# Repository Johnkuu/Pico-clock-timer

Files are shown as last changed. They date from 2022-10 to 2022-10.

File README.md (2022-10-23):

# Pico-clock-timer

A Pico based clock with a pomodoro timer. Includes a 3D printable case and two control buttons for keyboard enthusiasts. Powered with USB. No network needed. Uses slightly modified TM1637 library https://github.com/mcauser/micropython-tm1637. 

All necessary files are included in this repo.

## BOM
- Pi Pico
- TM1637.h screen
- 2x led and 2x 330-ohm resistors
- 2x Mechanical keyboard switches and keycaps.
- 3D printable case
- 4x screws (think M3 size) are needed to attach the bottom to the upper case
- Some super glue to attach the screen and leds to the case
- Wire (I used single core)
 
Pico

## Functionality
- On startup says "HIYA" as greeting
- Set time: Hours with left button, minutes with right button. When idling for 5 seconds, the clock starts running. If nothing is done in 5 seconds, sets time to 00.00
- After setting the time left button starts Pomodoro timer with 25 - 5 x4 cycle and ends with a 30-minute break. When it´s working time, the red led shines and during pauses, the blue led shines. When the timer is ready, the led´s goes off. On clock mode, no leds are on.
- When pressing button on right during the Pomodoro cycle the time skips to pause timer (30 min) and second press exits the timer
- The clock keeps the time even during when the pomodoro timer is running
- Adjustable screen light brightness with the left button. When pressing button the blue led blinks. Cycles from dark to brighter and when maxed out, starts from dimmer again.

## ROADMAP
- Better case that doesn´t require glue for attaching the screen.

## PINS:

- Display: CLK=Pin (0), DIO=Pin(1), GND=GND, 5V=VBUS
- LEDs:  ledred = Pin (9), Cathode (-) = GND and ledblue = Pin (27), Cathode (-) = GND (don´t forget the resistor!)
- Buttons: Button1 = Pin (13), GND and button2 = Pin (18), GND

## Instructions:
- Print case (use supports, doesn´t consume time/resources, looks better)
- Attach first the leds in the case with superglue (after setting the screen in place, it might be a slightly tight over there)
- Attach the keyboard switches to the case.
- Solder everything as instructed in PINS section, check everything is working before assembly. Drop all the .py -files into your pico in order to test the funtionality.
- Attach the screen with superglue, bear in your mind that it´s done in the right direction (check the text on the board)
- Attach the Pico to the bottom of the case. I used some filament from the 3D printer and heated the other end to make it flat. Some superglue in the holes in the bottom of the case and the filament through the Pico board holes and into the case holes.

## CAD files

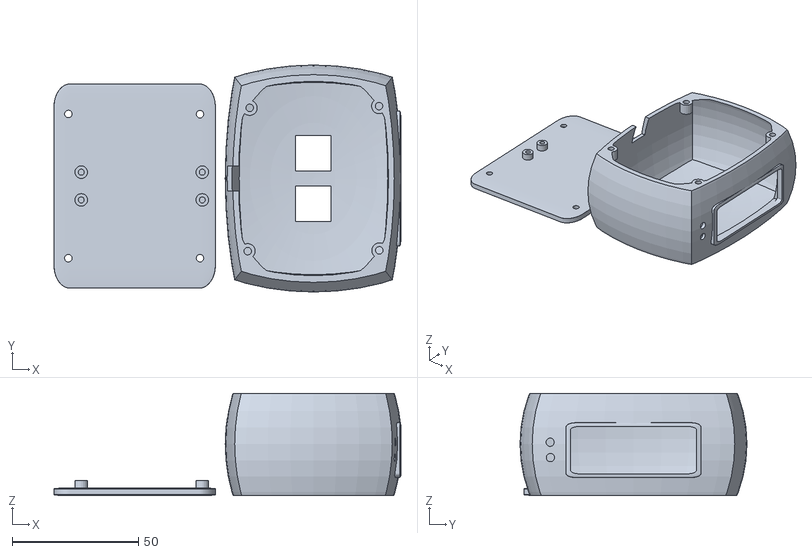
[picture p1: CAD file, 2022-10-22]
Pomodoro_timer_TM1637h.stl
137.6 x 90.0 x 40.5

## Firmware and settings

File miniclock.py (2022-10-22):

import tm1637
from machine import Pin
import time
import led

from machine import RTC

display = tm1637.TM1637(clk=Pin(0), dio=Pin(1))
 
button1 = Pin(13, Pin.IN, Pin.PULL_UP)
button2 = Pin(18, Pin.IN, Pin.PULL_UP)

b = 1 #(brightness of the display)

display.brightness(b) #Set brightness between 1-7)

def set_time():
    rtc = RTC()
#    hour = 20
#    minute = 40
    #rtc.datetime((year, month, day, weekday, hour, minute, second, 0))
    rtc.datetime((2022, 10, 16, 7, hour, minute, 0, 0))

#Clear all
def clear_disp():
    display.show("HIYA")
    time.sleep(1)
    display.show("    ")
    
def clock():
    # get system time
    local_time = str(time.localtime())
    parts = local_time.split(', ')
    hour = int(parts[3])
    minute = int(parts[4])
    second = int(parts[5])

    # Toggle colon when displaying time
    if second % 2:
        # setup HH.MM for display and print it
        display.numbers(hour, minute)
    else:
        # setup HH MM for display and print it
        display.number_time(hour, minute)
    time.sleep(0.5)

#while True:
#    clock()

def pomodore():
    display.show("    ") #tyhjennä näyttö
    rounds = 3 #aseta kierrosten määrä +1
    hour = 25 #aseta kierron aika
    minute = 0 # aseta kierron aika.
    while rounds > 0:
        b1 = button1.value()
        if not b1:
            led.ledredoff()
            break
        led.ledredon()
        display.number_time(hour, minute) # näytä lähtöaika
        hour = 24 #aseta seuraava aika
        minute = 59
        time.sleep(1)
        while True: #aloita kierrosten sisäinen looppi
            b1 = button1.value()
            if hour == 0 and minute == 0: # jos kaikki on nollilla aloita looppi jossa tarkastetaan kierrosten määrä tai hypätään pois
                if rounds == 0:# jos kaikki on nollilla ja kierrokset on nollilla, hyppää loopista pois
                    led.ledredoff()
                    break
                else: #muuten ajan ollessa nollilla laita 5 minuutin tauko käyntiin ja vähennä kierros
                    led.ledblueon()
                    led.ledredoff()
                    rounds -= 1
                    hour = 5
                    minute = 0
                    display.number_time(hour, minute) #Näytä 5 minsaa
                    time.sleep(1)
                    hour = 4 #näytä 4:49
                    minute = 59
                    led.ledblueon()
                    while True:
                        if minute == 0 and hour == 0: #jos minuutti ja sekuntti 0 hyppää pois loopista
                            display.number_time(hour, minute)
                            time.sleep(1)
                            hour = 24 #aseta aika takaisin normaaliin
                            minute = 59
                            break
                        if minute == 0: # jos minuutti 0 vähennä tunti ja aloita minuutti alusta
                            display.number_time(hour, minute)
                            minute = 59
                            hour -= 1
                        if not b1:
                            break
                        else: #muuten näytä aika ja vähennä sekuntti
                            display.number_time(hour, minute)
                        time.sleep(1)
                        minute-= 1
            if minute == 0: #jos vain sekuntit ovat nollilla, vähennä minuutti
                display.number_time(hour, minute)
                minute = 59
                hour -= 1
            if not b1:
                led.ledredoff()
                break    
            else: #muuten vähennä vain sekunti normaalisti
            # setup HH MM for display and print it
                display.number_time(hour, minute)
            time.sleep(1)
            minute-= 1
        hour = 25
        minute = 0
        display.number_time(hour, minute)
#Asettaa taukoajastimen 30 min
        hour = 30
        minute = 0
        display.number_time(hour, minute)
        time.sleep(1)
        hour = 29
        minute = 59
        time.sleep(1)
    
        while True: #Viimeinen 30 minuuttia, jonka jälkeen loppuu 00:00 5 s tauko ja koko silmukka päättyy
            b1 = button1.value()
            led.ledblueon()
            if hour == 0 and minute == 0:
                display.number_time(hour, minute)
                time.sleep(5)
                led.ledblueoff()
                break
            if minute == 0: 
                display.number_time(hour, minute)
                minute = 59
                hour -= 1
            if not b1:
                led.ledblueoff()
                led.ledredoff()
                break    
            else:
            # setup HH MM for display and print it
                display.number_time(hour, minute)
            time.sleep(1)
            minute-= 1
        
def buttons():
    b = 1
    while True:
        b1 = button1.value()
        b2 = button2.value()
        if not b1:
            print("Button 1 pressed!")
            led.ledblueon()
            if b == 7:
                b = 1
                print(b)
            else:
                b += 1
                print(b)
            display.brightness(b) #Set brightness between 1-7)
            time.sleep(0.5)
        if not b2:
            print("Button 2 pressed!")
            pomodore()
        else:
            led.ledblueoff()
            led.ledredoff()
            clock()

def set_time_manually():
    global hour
    global minute
    hour = 0
    minute = 0
    rounds = 0
    while True:
        b1 = button1.value()
        b2 = button2.value()   
        if not b2:
            hour = hour + 1
            display.number_time(hour,minute)
            time.sleep(0.1)
            print(hour)
            rounds = 0
            if hour == 23:
                hour = -1  
        if not b1:
            minute = minute + 1
            display.number_time(hour,minute)
            time.sleep(0.1)
            print(minute)
            rounds = 0
            if minute == 59:
                minute = -1        
        else:
            time.sleep(0.1)
            rounds += 1
            print(rounds)
            if rounds == 50:
                rtc = RTC()
                #hour = 20
                #minute = 40
                #rtc.datetime((year, month, day, weekday, hour, minute, second, 0))
                rtc.datetime((2022, 10, 16, 7, hour, minute, 0, 0))
                break

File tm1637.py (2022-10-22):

# MicroPython TM1637 quad 7-segment LED display driver

from micropython import const
from machine import Pin
from time import sleep_us, sleep_ms

TM1637_CMD1 = const(64)  # 0x40 data command
TM1637_CMD2 = const(192) # 0xC0 address command
TM1637_CMD3 = const(128) # 0x80 display control command
TM1637_DSP_ON = const(8) # 0x08 display on
TM1637_DELAY = const(10) # 10us delay between clk/dio pulses

# 0-9, a-z, blank, dash, star
_SEGMENTS = bytearray(b'\x3F\x06\x5B\x4F\x66\x6D\x7D\x07\x7F\x6F\x77\x7C\x39\x5E\x79\x71\x3D\x76\x06\x1E\x76\x38\x55\x54\x3F\x73\x67\x50\x6D\x78\x3E\x1C\x2A\x76\x6E\x5B\x00\x40\x63')

class TM1637(object):
    """Library for quad 7-segment LED modules based on the TM1637 LED driver."""
    def __init__(self, clk, dio, brightness=7):
        self.clk = clk
        self.dio = dio

        if not 0 <= brightness <= 7:
            raise ValueError("Brightness out of range")
        self._brightness = brightness

        self.clk.init(Pin.OUT, value=0)
        self.dio.init(Pin.OUT, value=0)
        sleep_us(TM1637_DELAY)

        self._write_data_cmd()
        self._write_dsp_ctrl()

    def _start(self):
        self.dio(0)
        sleep_us(TM1637_DELAY)
        self.clk(0)
        sleep_us(TM1637_DELAY)

    def _stop(self):
        self.dio(0)
        sleep_us(TM1637_DELAY)
        self.clk(1)
        sleep_us(TM1637_DELAY)
        self.dio(1)

    def _write_data_cmd(self):
        # automatic address increment, normal mode
        self._start()
        self._write_byte(TM1637_CMD1)
        self._stop()

    def _write_dsp_ctrl(self):
        # display on, set brightness
        self._start()
        self._write_byte(TM1637_CMD3 | TM1637_DSP_ON | self._brightness)
        self._stop()

    def _write_byte(self, b):
        for i in range(8):
            self.dio((b >> i) & 1)
            sleep_us(TM1637_DELAY)
            self.clk(1)
            sleep_us(TM1637_DELAY)
            self.clk(0)
            sleep_us(TM1637_DELAY)
        self.clk(0)
        sleep_us(TM1637_DELAY)
        self.clk(1)
        sleep_us(TM1637_DELAY)
        self.clk(0)
        sleep_us(TM1637_DELAY)

    def brightness(self, val=None):
        """Set the display brightness 0-7."""
        # brightness 0 = 1/16th pulse width
        # brightness 7 = 14/16th pulse width
        if val is None:
            return self._brightness
        if not 0 <= val <= 7:
            raise ValueError("Brightness out of range")

        self._brightness = val
        self._write_data_cmd()
        self._write_dsp_ctrl()

    def write(self, segments, pos=0):
        """Display up to 4 segments moving right from a given position.
        The MSB in the 2nd segment controls the colon between the 2nd
        and 3rd segments."""
        if not 0 <= pos <= 3:
            raise ValueError("Position out of range")
        self._write_data_cmd()
        self._start()

        self._write_byte(TM1637_CMD2 | pos)
        for seg in segments:
            self._write_byte(seg)
        self._stop()
        self._write_dsp_ctrl()

    def encode_digit(self, digit):
        """Convert a character 0-9, a-f to a segment."""
        return _SEGMENTS[digit & 0x0f]

    def encode_string(self, string):
        """Convert an up to 4 character length string containing 0-9, a-f,
        space, dash to an array of segments, matching the length of the
        source string."""
        segments = bytearray(len(string))
        for i in range(len(string)):
            segments[i] = self.encode_char(string[i])
        return segments

    def encode_char(self, char):
        """Convert a character 0-9, a-z, space or dash to a segment."""
        o = ord(char)
        if o == 32:
            return _SEGMENTS[36] # space
        if o == 42:
            return _SEGMENTS[38] # star/degrees
        if o == 45:
            return _SEGMENTS[37] # dash
        if o >= 65 and o <= 90:
            return _SEGMENTS[o-55] # uppercase A-Z
        if o >= 97 and o <= 122:
            return _SEGMENTS[o-87] # lowercase a-z
        if o >= 48 and o <= 57:
            return _SEGMENTS[o-48] # 0-9
        raise ValueError("Character out of range: {:d} '{:s}'".format(o, chr(o)))

    def hex(self, val):
        """Display a hex value 0x0000 through 0xffff, right aligned."""
        string = '{:04x}'.format(val & 0xffff)
        self.write(self.encode_string(string))

    def number(self, num):
        """Display a numeric value -999 through 9999, right aligned."""
        # limit to range -999 to 9999
        num = max(-999, min(num, 9999))
        string = '{0: >4d}'.format(num)
        self.write(self.encode_string(string))
        
    def number_time(self, num1, num2, colon=False): #This was custom made, to get the time presented without the colon between the seconds.
        """Display two numeric values -9 through 99, with leading zeros
        and separated by a colon."""
        num1 = max(-9, min(num1, 99))
        num2 = max(-9, min(num2, 99))
        segments = self.encode_string('{0:0>2d}{1:0>2d}'.format(num1, num2))
        self.write(segments)

    def numbers(self, num1, num2, colon=True):
        """Display two numeric values -9 through 99, with leading zeros
        and separated by a colon."""
        num1 = max(-9, min(num1, 99))
        num2 = max(-9, min(num2, 99))
        segments = self.encode_string('{0:0>2d}{1:0>2d}'.format(num1, num2))
        if colon:
            segments[1] |= 0x80 # colon on
        self.write(segments)

    def temperature(self, num):
        if num < -9:
            self.show('lo') # low
        elif num > 99:
            self.show('hi') # high
        else:
            string = '{0: >2d}'.format(num)
            self.write(self.encode_string(string))
        self.write([_SEGMENTS[38], _SEGMENTS[12]], 2) # degrees C

    def show(self, string, colon=False):
        segments = self.encode_string(string)
        if len(segments) > 1 and colon:
            segments[1] |= 128
        self.write(segments[:4])

    def scroll(self, string, delay=250):
        segments = string if isinstance(string, list) else self.encode_string(string)
        data = [0] * 8
        data[4:0] = list(segments)
        for i in range(len(segments) + 5):
            self.write(data[0+i:4+i])
            sleep_ms(delay)

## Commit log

2022-10-22 Script for the clock / timer
    Add all four files to your Pico
2022-10-22 Added 3D printable case
    STL file for printing the case
    [Pomodoro_timer_TM1637h.stl]
